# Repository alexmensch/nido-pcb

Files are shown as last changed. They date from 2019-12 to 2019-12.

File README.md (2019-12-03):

*This respository holds the [Eagle](https://www.autodesk.com/products/eagle/overview) schematic and board CAD files for the Nido smart thermostat sensor printed circuit board (PCB). This PCB connects directly to the Raspberry Pi GPIO header for the simplest possible installation. If you're looking for instructions on how to run Nido on a Raspberry Pi, see https://github.com/alexmensch/nido for instructions and the full project background.*

## Nido PCB v2.0 (Top | CAD | Bottom)

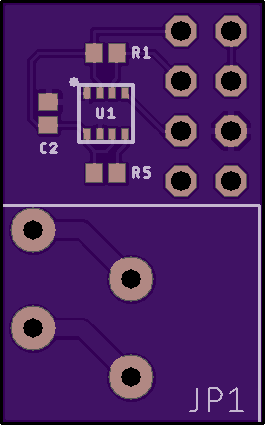
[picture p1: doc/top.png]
Nido PCB Top
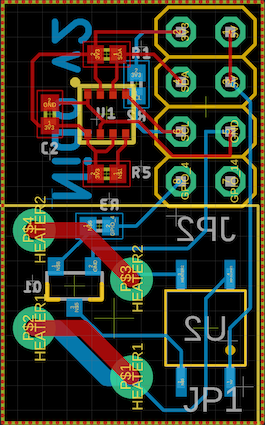
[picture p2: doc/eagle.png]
Nido PCB CAD
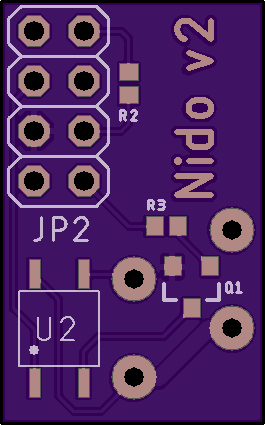
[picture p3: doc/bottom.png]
Nido PCB Bottom
  

## Bill of Materials (BOM)

Item | Reference | Qty. | Manufacturer  | Part Number   | Package | Type | Notes
:----|:----------|:-----|:--------------|:--------------|:--------|:-----|:-----
1    |JP1        |1     |TE Connectivity|1986712-2		  |         |TH    |Mount on top of board
2    |Q1         |1     |Diodes Inc     |BCW66HTA       |SOT-23-3 |SMD   |
3    |R1-3,R5    |4     |Yageo          |RC0402JR-0710KL|0402     |SMD   |
4    |C2         |1     |Samsung        |CL05A104MP5NNNC|0402     |SMD   |
5    |U2         |1     |IXYS           |CPC1017NTR	    |4-SOP    |SMD   |Align dot on chip with silkscreen dot
6    |U1         |1     |Bosch          |BME280         |8-LGA    |SMD   |Align dot on chip with silkscreen dot
7    |JP2        |1     |Sullins        |PPTC042LFBN-RC |         |TH    |Mount on bottom of board

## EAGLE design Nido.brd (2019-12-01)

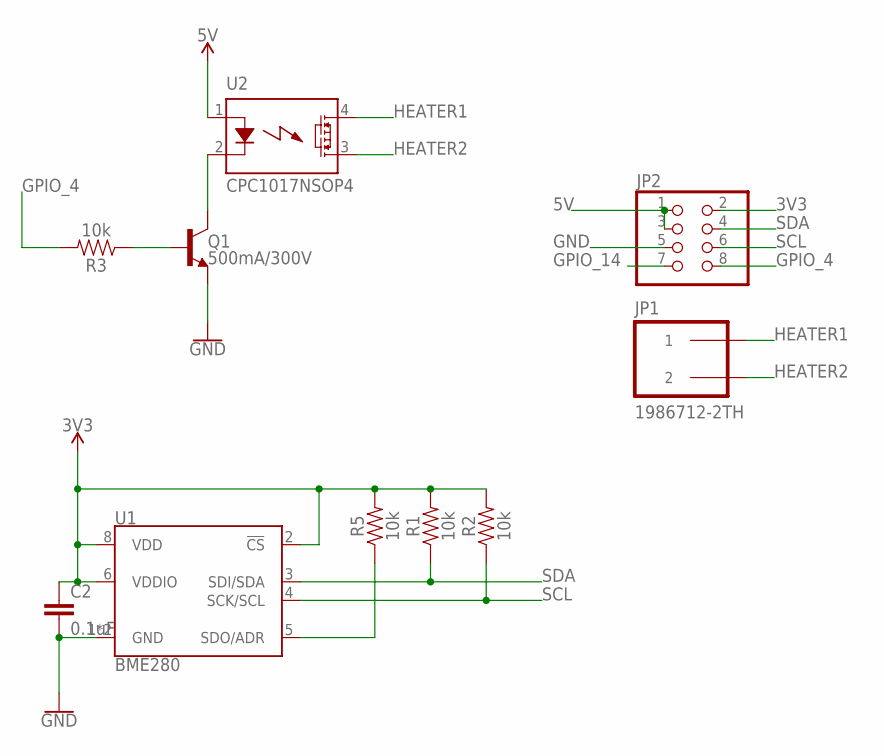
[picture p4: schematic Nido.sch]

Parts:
C2: 0.1uF; 0402
JP1: 1986712-2TH; 1986712-2
JP2: PINHD-2X4; 2X04
Q1: 500mA/300V; SOT23-3
R1, R2, R3, R5: 10k; 0402
U1: BME280; LGA-8-2.5X2.5
U2: CPC1017NSOP4; CPC1017N

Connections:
3V3: C2.1, JP2.2, R1.2, R2.2, R5.2, U1.2 (!CS), U1.6 (VDDIO), U1.8 (VDD)
5V: JP2.1, JP2.3, U2.1 (+CONTROL)
GND: C2.2, JP2.5, Q1.2 (E), U1.1 (GND), U1.7 (GND)
GPIO_4: JP2.8, R3.2
GPIO_14: JP2.7
HEATER1: JP1.P$1 (1), JP1.P$2 (1), U2.4 (LOAD2)
HEATER2: JP1.P$3 (2), JP1.P$4 (2), U2.3 (LOAD1)
unnamed: R5.1, U1.5 (SDO/ADR)
unnamed: Q1.3 (C), U2.2 (-CONTROL)
unnamed: Q1.1 (B), R3.1
SCL: JP2.6, R2.1, U1.4 (SCK/SCL)
SDA: JP2.4, R1.1, U1.3 (SDI/SDA)

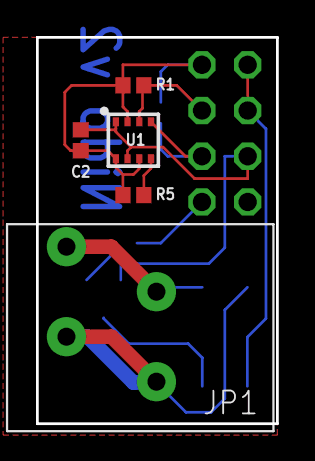
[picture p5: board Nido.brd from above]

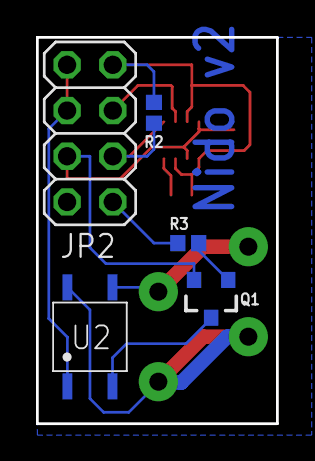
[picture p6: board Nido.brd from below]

Board: 2 copper layers, 13.3 x 21.5 mm, 10 parts (5 on the bottom side), 11 nets.

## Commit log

2019-08-05 Initial commit of Eagle board and schematic files
    [Nido.brd, Nido.sch]
2019-08-06 Updated board components, added PCB photos
    [Nido.brd, Nido.sch]
2019-08-06 Removed unused nets
    [Nido.sch]
2019-12-01 Updated Nido PCB v2 files
    [Nido.brd, Nido.sch]
2019-12-01 Updated CAD image

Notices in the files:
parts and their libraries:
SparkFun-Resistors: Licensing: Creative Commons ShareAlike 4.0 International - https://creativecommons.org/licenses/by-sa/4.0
